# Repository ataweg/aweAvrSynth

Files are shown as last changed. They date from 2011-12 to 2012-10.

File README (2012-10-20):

My version of a virtual analog synthesizer, derived from Meeblip synthesizer, with much enhancements and improvements:
The most important are:
 * Much more of the sound parameters can be controlled via MIDI, the expanded MIDI mapping for my keyboard is based on the knobs and sliders of a QX49
 * Modified waveform tables, A and B have separate oscillator wavetable parameters.
 * Re-introducing some of the switches and controls from Meeblip V1.05, this can be controlled via MIDI
 * Master volume control via MIDI. It can also be raised the volume.
 * Ring Modulator for metallic sounds
 * Noise generator now makes more or less white noise - new algorithm
 * VCFENVMOD now ranging from -128 to +127.
 * PWM generation needs only one sawooth table.
 * Patch 1 has a default setting and can not be overwritten.
 * The volume is keep constant, when OSC B is switched on or off.
 * The button "dco fm" and "anti-alias" sacrificed for "ring modulator" and "transpose"

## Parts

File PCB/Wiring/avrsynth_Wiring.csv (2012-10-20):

ref | value | footprint | Feld1 | Feld2 | Feld3 | Feld4 | Feld5 | Feld6 | Feld7 | Feld8
_P1 | CONN_10
_P2 | CONN_5
_P4 | CONN_8
_P6 | CONN_5
_P9 | CONN_3
_P10 | CONN_3
_P11 | CONN_3
_P13 | CONN_3
_P16 | CONN_3
C1 | 10uF/35V | C1V5
C2 | 100nF | C2
D1 | LED red | LED_5mm
D3 | 1N4148 | DO35-3
D4 | 1N4148 | DO35-3
D5 | 1N4148 | DO35-3
D6 | 1N4148 | DO35-3
D7 | 1N4148 | DO35-3
D8 | 1N4148 | DO35-3
D9 | 1N4148 | DO35-3
D10 | 1N4148 | DO35-3
D11 | 1N4148 | DO35-3
D12 | 1N4148 | DO35-3
D13 | 1N4148 | DO35-3
D14 | 1N4148 | DO35-3
D15 | 1N4148 | DO35-3
D16 | 1N4148 | DO35-3
D17 | 1N4148 | DO35-3
D18 | 1N4148 | DO35-3
D19 | 1N4148 | DO35-3
D20 | 1N4148 | DO35-3
D21 | 1N4148 | DO35-3
D22 | 1N4148 | DO35-3
E1 | KNOPF 14M-4 SW
E2 | KNOPF 14M-4 SW
E3 | KNOPF 14M-4 SW
E4 | KNOPF 14M-4 SW
E5 | KNOPF 14M-4 SW
E6 | KNOPF 14M-4 SW
E7 | KNOPF 14M-4 SW
E8 | KNOPF 14M-4 SW
E9 | KNOPF 20M-4 SW
E11 | DECKEL 14M BL
E12 | DECKEL 14M BL
E13 | DECKEL 14M BL
E14 | DECKEL 14M BL
E15 | DECKEL 14M BL
E16 | DECKEL 14M BL
E17 | DECKEL 14M BL
E18 | DECKEL 14M BL
E19 | DECKEL 20M RT
E21 | ZEIGER 14-1 SW
E22 | ZEIGER 14-1 SW
E23 | ZEIGER 14-1 SW
E24 | ZEIGER 14-1 SW
E25 | ZEIGER 14-1 SW
E26 | ZEIGER 14-1 SW
E27 | ZEIGER 14-1 SW
E28 | ZEIGER 14-1 SW
E29 | ZEIGER 20-1 SW
E33 | Flachbandkabel 10-polig 30cm
E34 | 10-pol Schneidklemm-Buchse
E35 | Gehäuse
E36 | IC Fassungen
J1 | JACK-STEREO 6.35 | Jack-6.35-Stereo
J2 | JACK_2P
J3 | JACK-STEREO-SW 3.5 | Jack-3.5-Stereo-SW
J4 | JACK-STEREO-SW 6.35 | Jack-6.35-Stereo-SW
J5 | USB_2 |  | Reichelt | USB BW | VCC | D+ | D- | GND
P1 | SUBD-F09D
P2 | DIN-BUCHSE-5POL
P3 | DIN-BUCHSE-5POL
P4 | DIN-BUCHSE-5POL
P5 | 9V-BATTERIE-CLIP
P6 | CONN_5X2
RV1 | 47K LIN | poti_4mm | Pollin | 94-240415
RV2 | 47K LIN | poti_4mm | Pollin | 94-240415
RV3 | 47K LIN | poti_4mm | Pollin | 94-240415
RV4 | 47K LIN | poti_4mm | Pollin | 94-240415
RV5 | 47K LIN | poti_4mm | Pollin | 94-240415
RV6 | 47K LIN | poti_4mm | Pollin | 94-240415
RV7 | 47K LIN | poti_4mm | Pollin | 94-240415
RV8 | 47K LIN | poti_4mm | Pollin | 94-240415
RV9 | 47K LOG | poti_4mm
SW1 | SWITCH_INV | Kippschalter | Pollin | 94-420430
SW2 | SWITCH_INV | Kippschalter | Pollin | 94-420430
SW3 | SWITCH_INV | Kippschalter | Pollin | 94-420430
SW4 | SWITCH_INV | Kippschalter | Pollin | 94-420430
SW5 | SWITCH_INV | Kippschalter | Pollin | 94-420430
SW6 | SWITCH_INV | Kippschalter | Pollin | 94-420430
SW7 | SWITCH_INV | Kippschalter | Pollin | 94-420430
SW8 | SWITCH_INV | Kippschalter | Pollin | 94-420430
SW9 | SWITCH_INV | Kippschalter | Pollin | 94-420430
SW10 | SWITCH_INV | Kippschalter | Pollin | 94-420430
SW11 | SWITCH_INV | Kippschalter | Pollin | 94-420430
SW12 | SWITCH_INV | Kippschalter | Pollin | 94-420430
SW13 | SWITCH_INV | Kippschalter | Pollin | 94-420430
SW14 | SWITCH_INV | Kippschalter | Pollin | 94-420430
SW15 | SWITCH_INV | Kippschalter | Pollin | 94-420430
SW16 | SWITCH_INV | Kippschalter | Pollin | 94-420430
SW17 | KDR16 | KDR16
SW18 | PHAP-3301 | PHAP-3301

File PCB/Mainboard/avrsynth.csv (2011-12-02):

ref | value | footprint | Feld1 | Feld2 | Feld3 | Feld4 | Feld5 | Feld6 | Feld7 | Feld8
_NP1 | HOLE | HOLE_32
_NP2 | HOLE | HOLE_32
_NP3 | HOLE | HOLE_32
_NP4 | HOLE | HOLE_32
C1 | 330nF | C2
C2 | 100nF | C2
C3 | 10uF/35V | C1V5
C4 | 100nF | C1
C5 | 100nF | C1
C6 | 33pF KER | C1
C7 | 33pF KER | C1
C8 | 100nF | C1
C9 | 47uF/25V | C1V5
C10 | 100nF | C2
C11 | 10uF/35V | C1V5
C12 | 10uF/35V | C1V5
C13 | 1uF/25V | C1V5
C14 | 220uF/25V | C2V8
C15 | 10nF | C2
C16 | 1nF | C2
C17 | 47nF | C2
C18 | 470pF 2,5% | C2 | Reichelt | FKP-2-1000 470P
C19 | 470pF 2,5% | C2 | Reichelt | FKP-2-1000 470P
C20 | 100nF | C2
C21 | 100nF | C2
C22 | 470uF/25V | C2V10
C23 | 10uF/35V | C1V5
C24 | 1uF/25V | C1V5
C25 | 1uF/25V | C1V5
C26 | 1uF/25V | C1V5
C27 | 1uF/25V | C1V5
C28 | 1uF/25V | C1V5
D1 | 1N4001 | DO41-4
D2 | BAT42 | DO35-3
D4 | 1N4148 | DO35-3
D9 | 1N4148 | DO35-3
IC1 | LM78L05Z | TO92-123
IC2 | ATMEGA32-P | DIP-40__600
IC3 | MAX232 | DIP-16__300
IC4 | LM386 | DIP-8__300
IC5 | AD7302 | DIP-20__300
IC6 | MCP6002 | DIP-8__300
JP1 | JUMPER | pin_array_2x1
L1 | 10uH | R5
OK1 | 6N138 | DIP-8__300
P1 | CONN_10 | PS25_10G
P2 | CONN_5 | PS25_5G
P3 | CONN_3X2 | pin_array_3x2
P4 | CONN_8 | PS25_8G
P6 | CONN_5 | PS25_5G
P9 | CONN_3 | PS25_3G
P10 | CONN_3 | PS25_3G
P11 | CONN_3 | PS25_3G
P12 | CONN_5X2 | pin_array_5x2
P14 | CONN_3 | PS25_3G
P16 | CONN_3 | PS25_3G
Q5 | BC557B | TO92
Q6 | BC547C | TO92
Q7 | BC557B | TO92
Q8 | BC547C | TO92
R1 | 10K | R4
R2 | 1K 0,1% | R4
R3 | 220R | R4
R4 | 270K 0,1% | R4
R11 | 10K 0,1% | R4
R13 | 4K7 1% | R4
R14 | 24K 1% | R4
R16 | 10R | R4
R21 | 22R | R4
R23 | 10K | R4
R24 | 470R | R4
R25 | 470R | R4
R26 | 220R | R4
R27 | 220R | R4
R28 | 220R | R4
R29 | 4K7 | R4
R30 | 1K5 | R4
R31 | 33K | R4
R32 | 220R | R4
R33 | 220R | R4
R34 | 15K | R4
R35 | 220R | R4
R36 | 220R | R4
R37 | 220R | R4
R38 | 4K7 | R4
R39 | 1K5 | R4
R40 | 33K | R4
R45 | 10K | R4
R46 | 10K | R4
X1 | 16MHz | HC-49V

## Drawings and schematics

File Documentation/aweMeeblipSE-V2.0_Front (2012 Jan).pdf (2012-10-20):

## Axel Werner

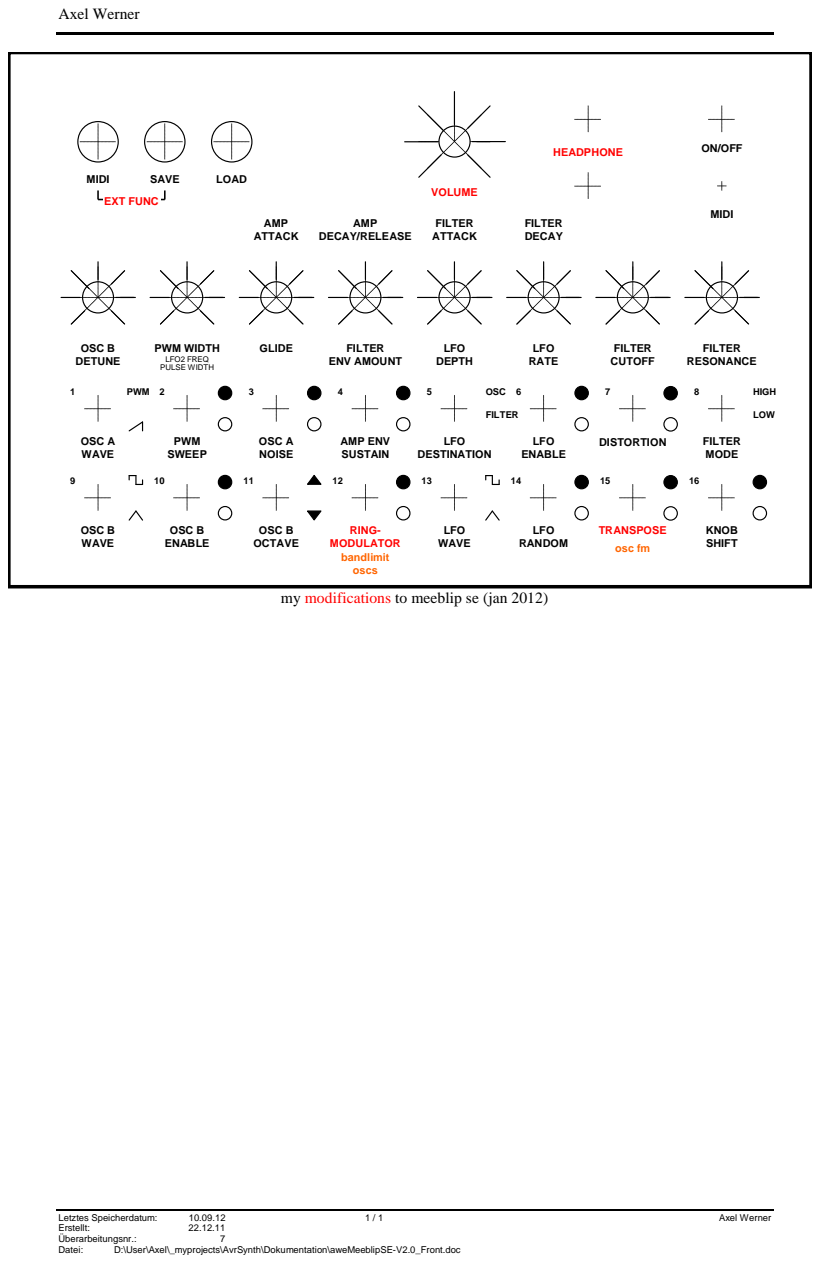
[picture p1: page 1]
Letztes Speicherdatum:; Axel Werner; Erstellt:; Überarbeitungsnr.:; Datei:; D:\User\Axel\_myprojects\AvrSynth\Dokumentation\aweMeeblipSE-V2.0_Front.doc; OSC B DETUNE; PWM WIDTH LFO2 FREQ PULSE WIDTH; GLIDE; FILTER; ENV AMOUNT; LFO DEPTH; LFO RATE; FILTER CUTOFF; FILTER RESONANCE; OSC A WAVE; PWM SWEEP; AMP ENV SUSTAIN; LFO DESTINATION; LFO ENABLE; OSC A NOISE; FILTER MODE; OSC B WAVE; OSC B ENABLE; OSC B OCTAVE; RING- MODULATOR; LFO WAVE; LFO RANDOM; KNOB SHIFT; VOLUME; AMP ATTACK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

my modifications to meeblip se (jan 2012)

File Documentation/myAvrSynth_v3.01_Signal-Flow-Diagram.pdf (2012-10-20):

## LFO

## DCO A

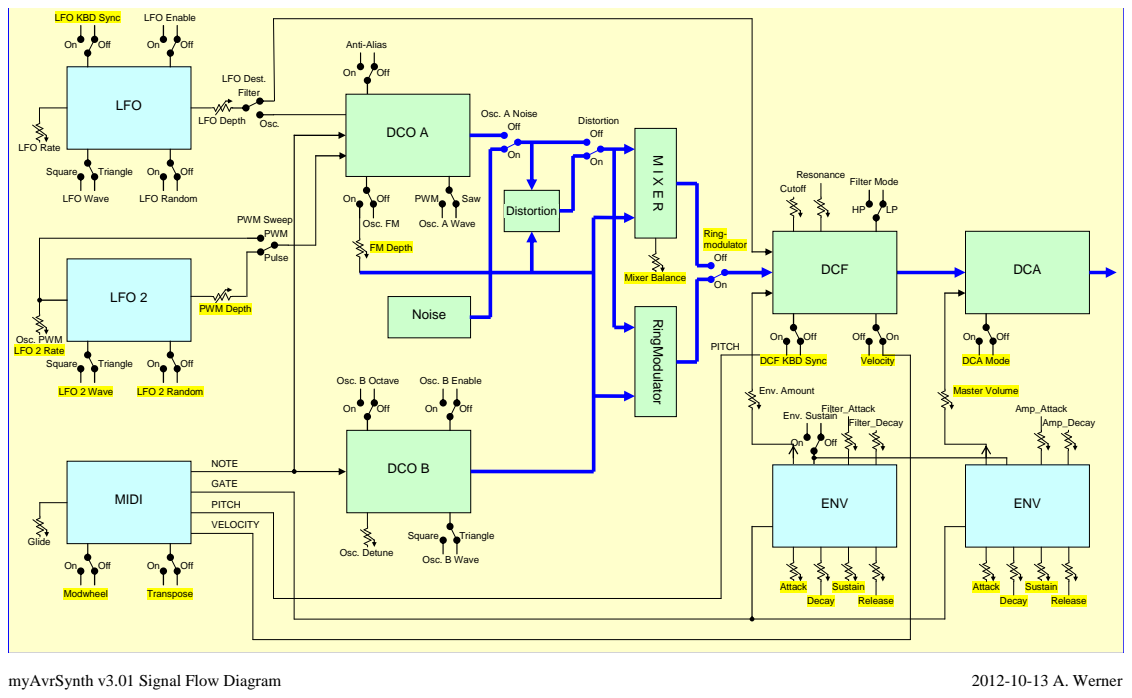
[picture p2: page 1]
MIDI; Glide; Off; Transpose; Modwheel; GATE; NOTE; PITCH; VELOCITY; Noise; DCO B; Osc. Detune; Triangle; Osc. B Wave; Square; Osc. B Enable; Osc. B Octave; LFO Rate; Filter; LFO Dest.; LFO Enable; LFO Wave; LFO Random; Pulse; PWM Sweep PWM; PWM Depth; LFO 2 Rate; LFO 2; LFO 2 Wave; LFO 2 Random; Osc. PWM; Anti-Alias; Osc. FM; FM Depth; Saw; Osc. A Wave; PWM; RingModulator M I X E R; Osc. A Noise; Distortion; Mixer Balance; Ring- modulator; Env. Amount; Master Volume; DCA; DCA Mode; Velocity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

LFO KBD Sync

Osc. LFO Depth

DCF KBD Sync

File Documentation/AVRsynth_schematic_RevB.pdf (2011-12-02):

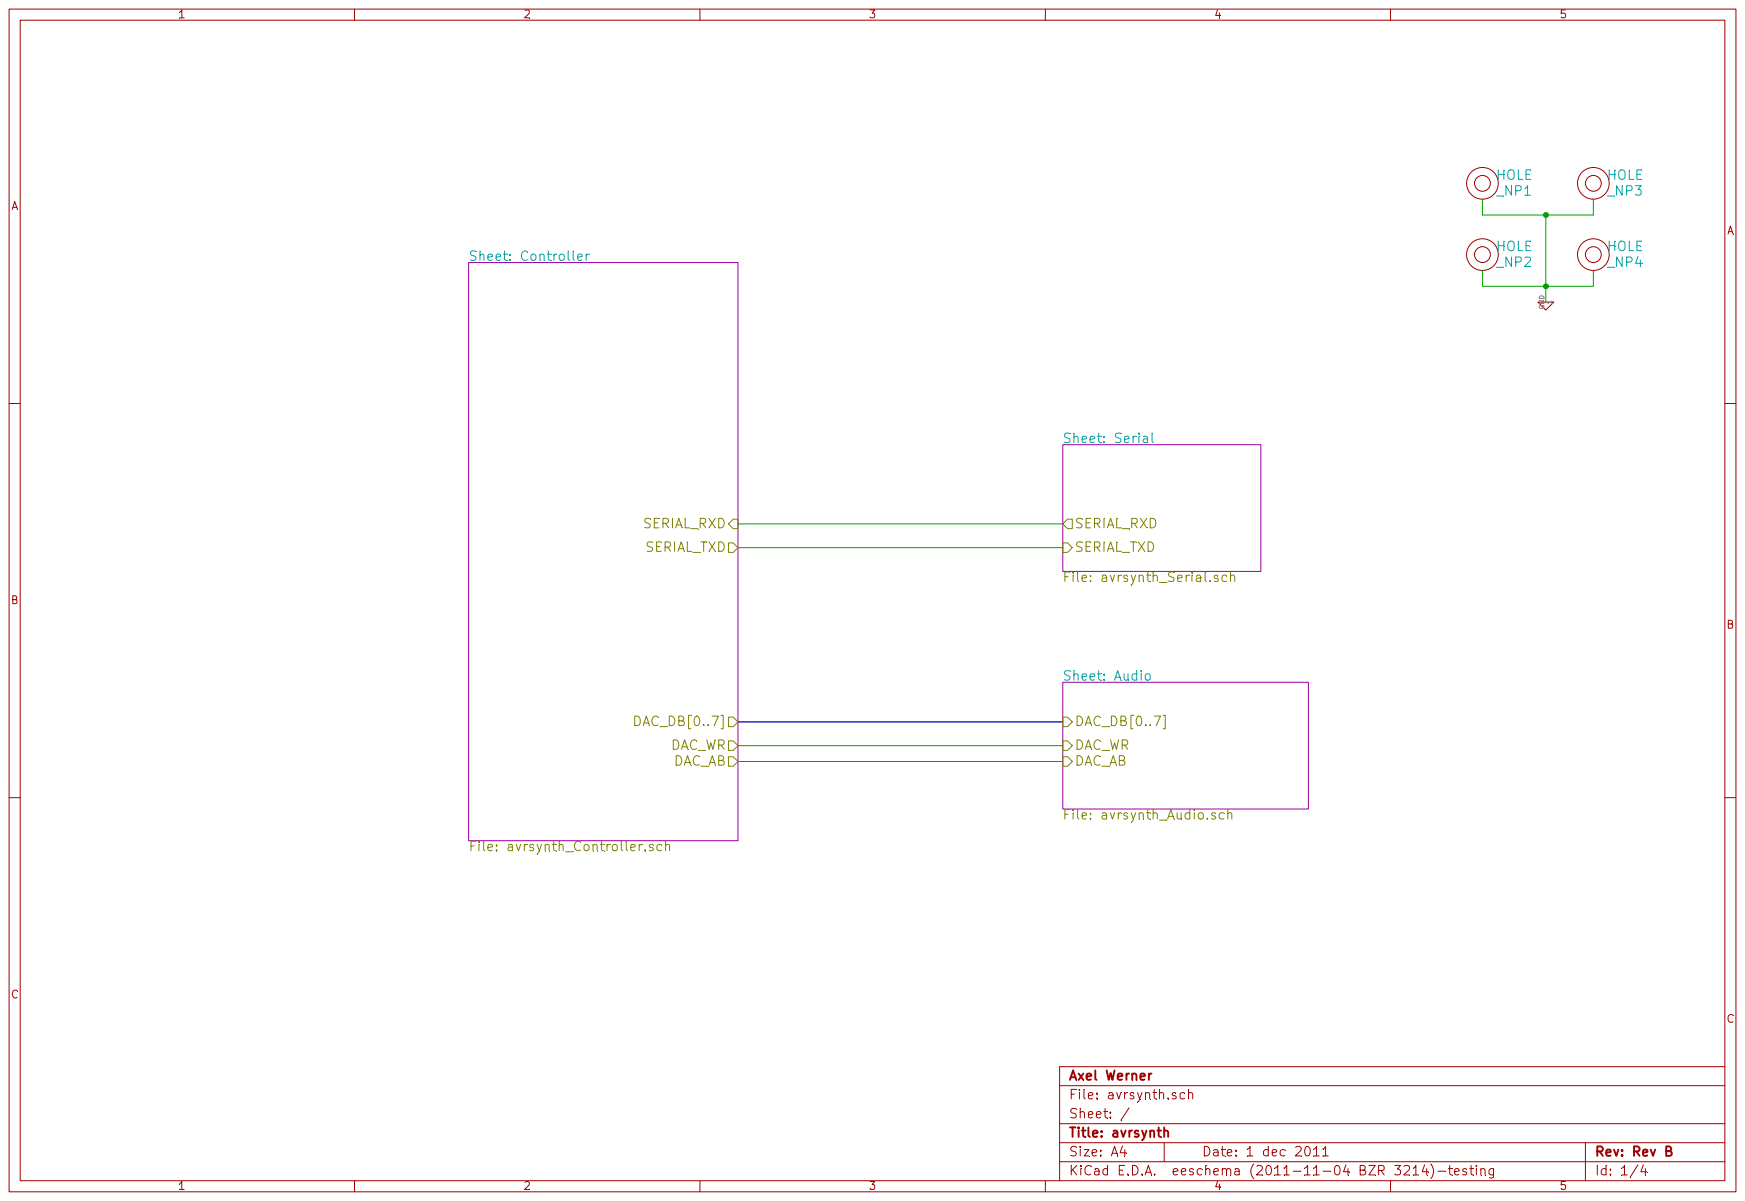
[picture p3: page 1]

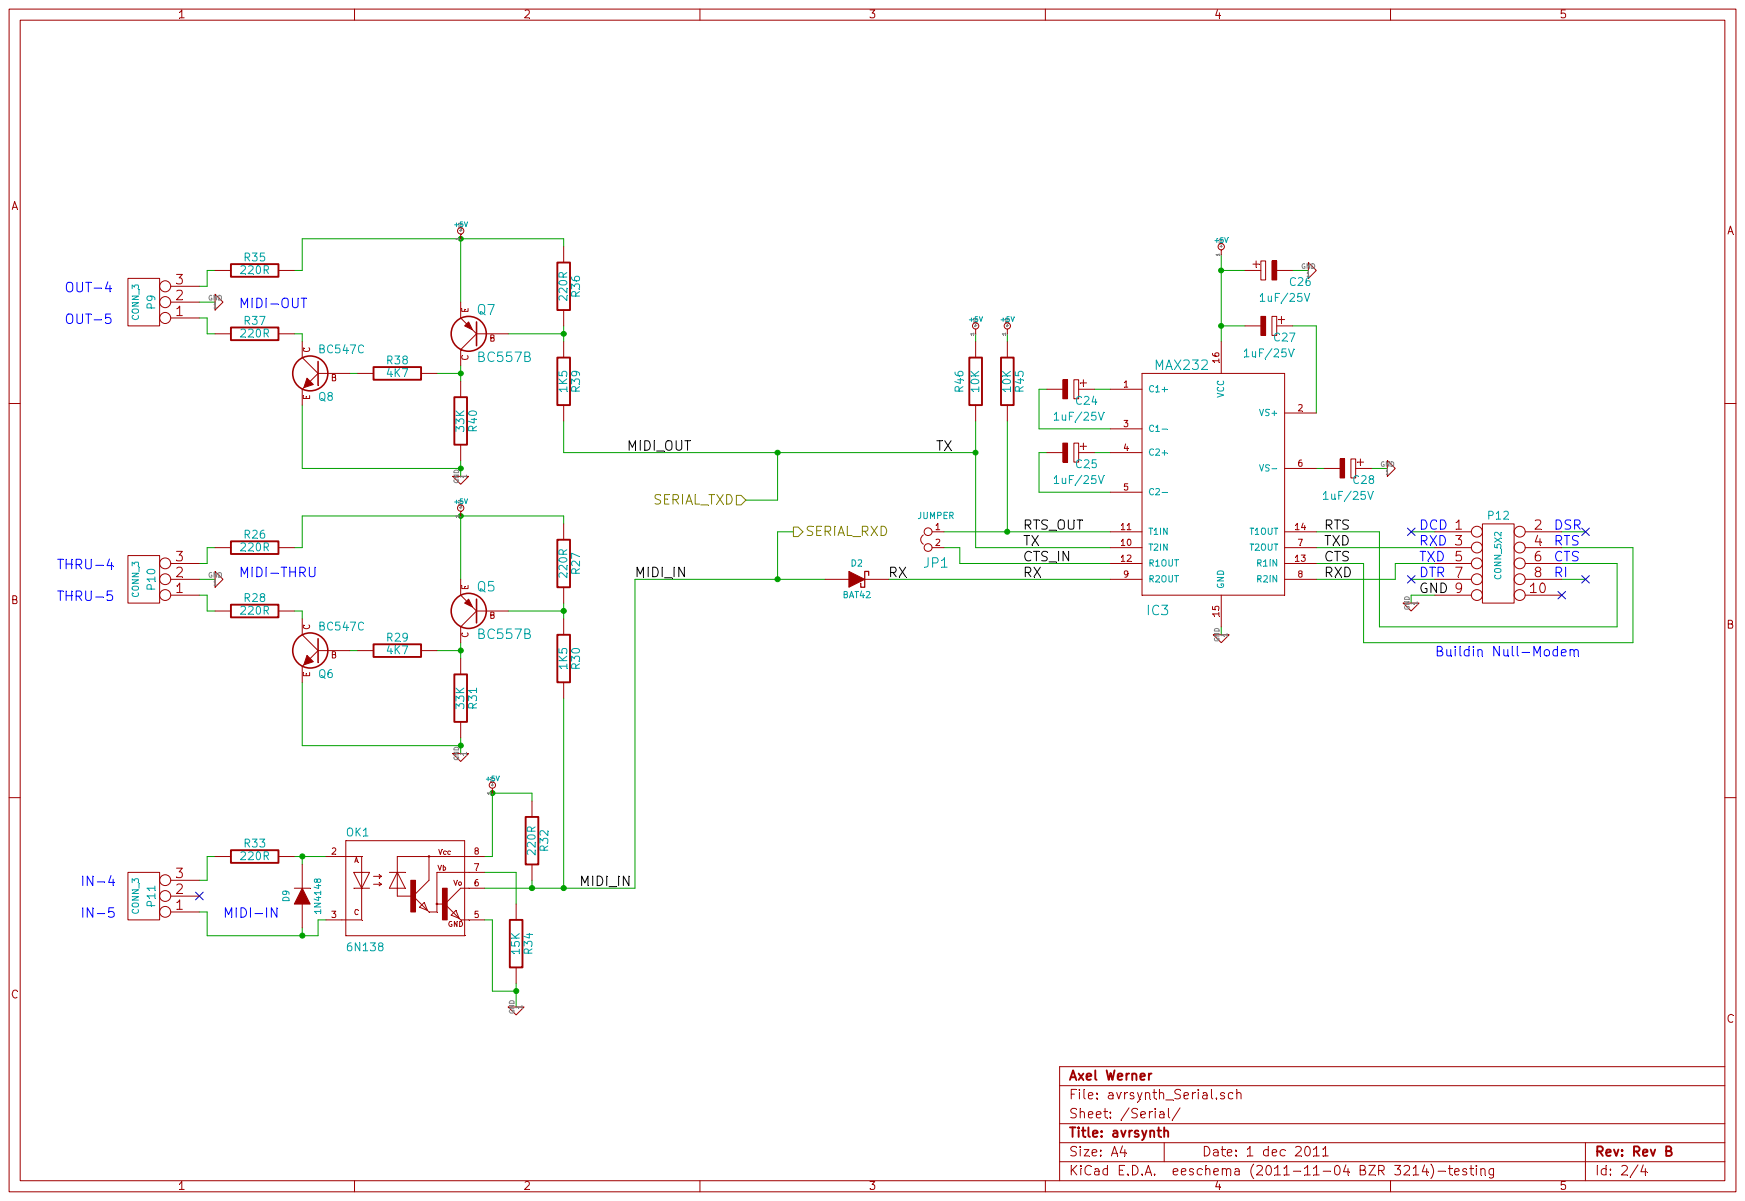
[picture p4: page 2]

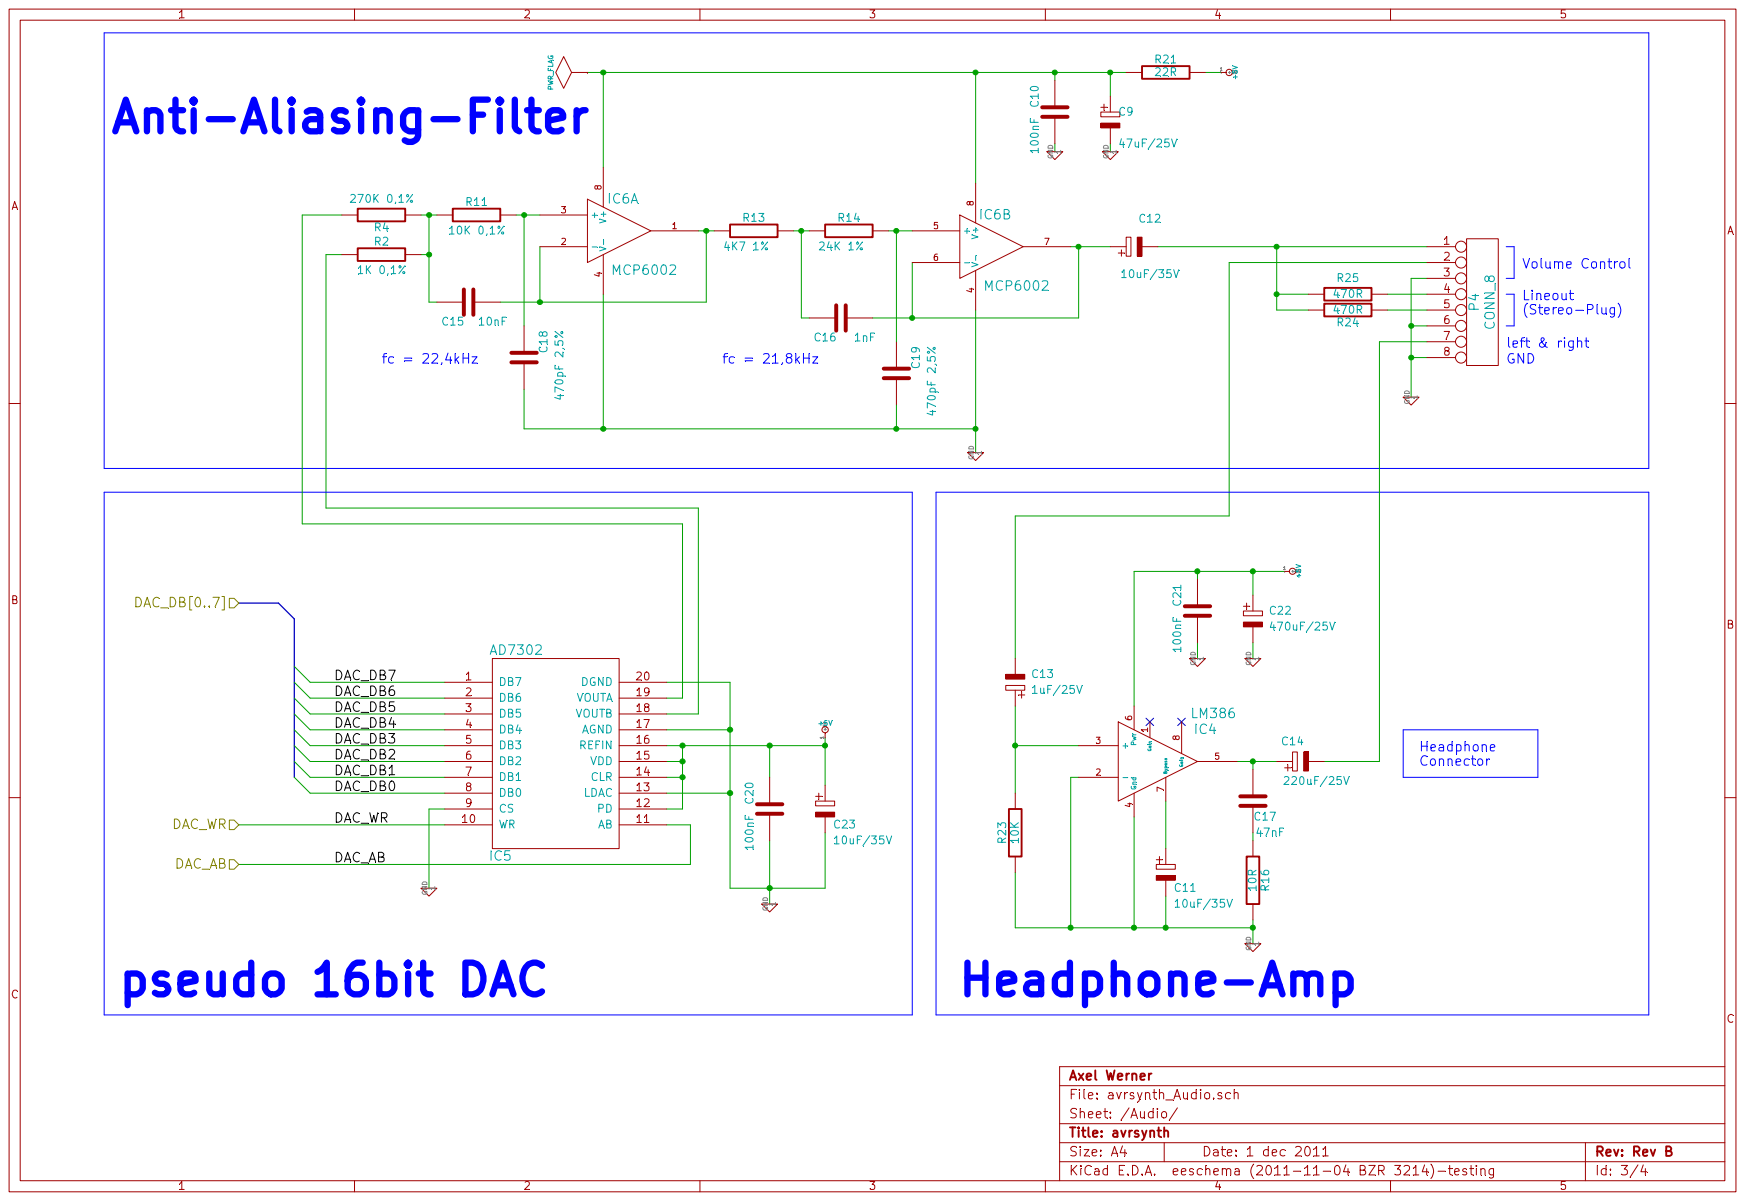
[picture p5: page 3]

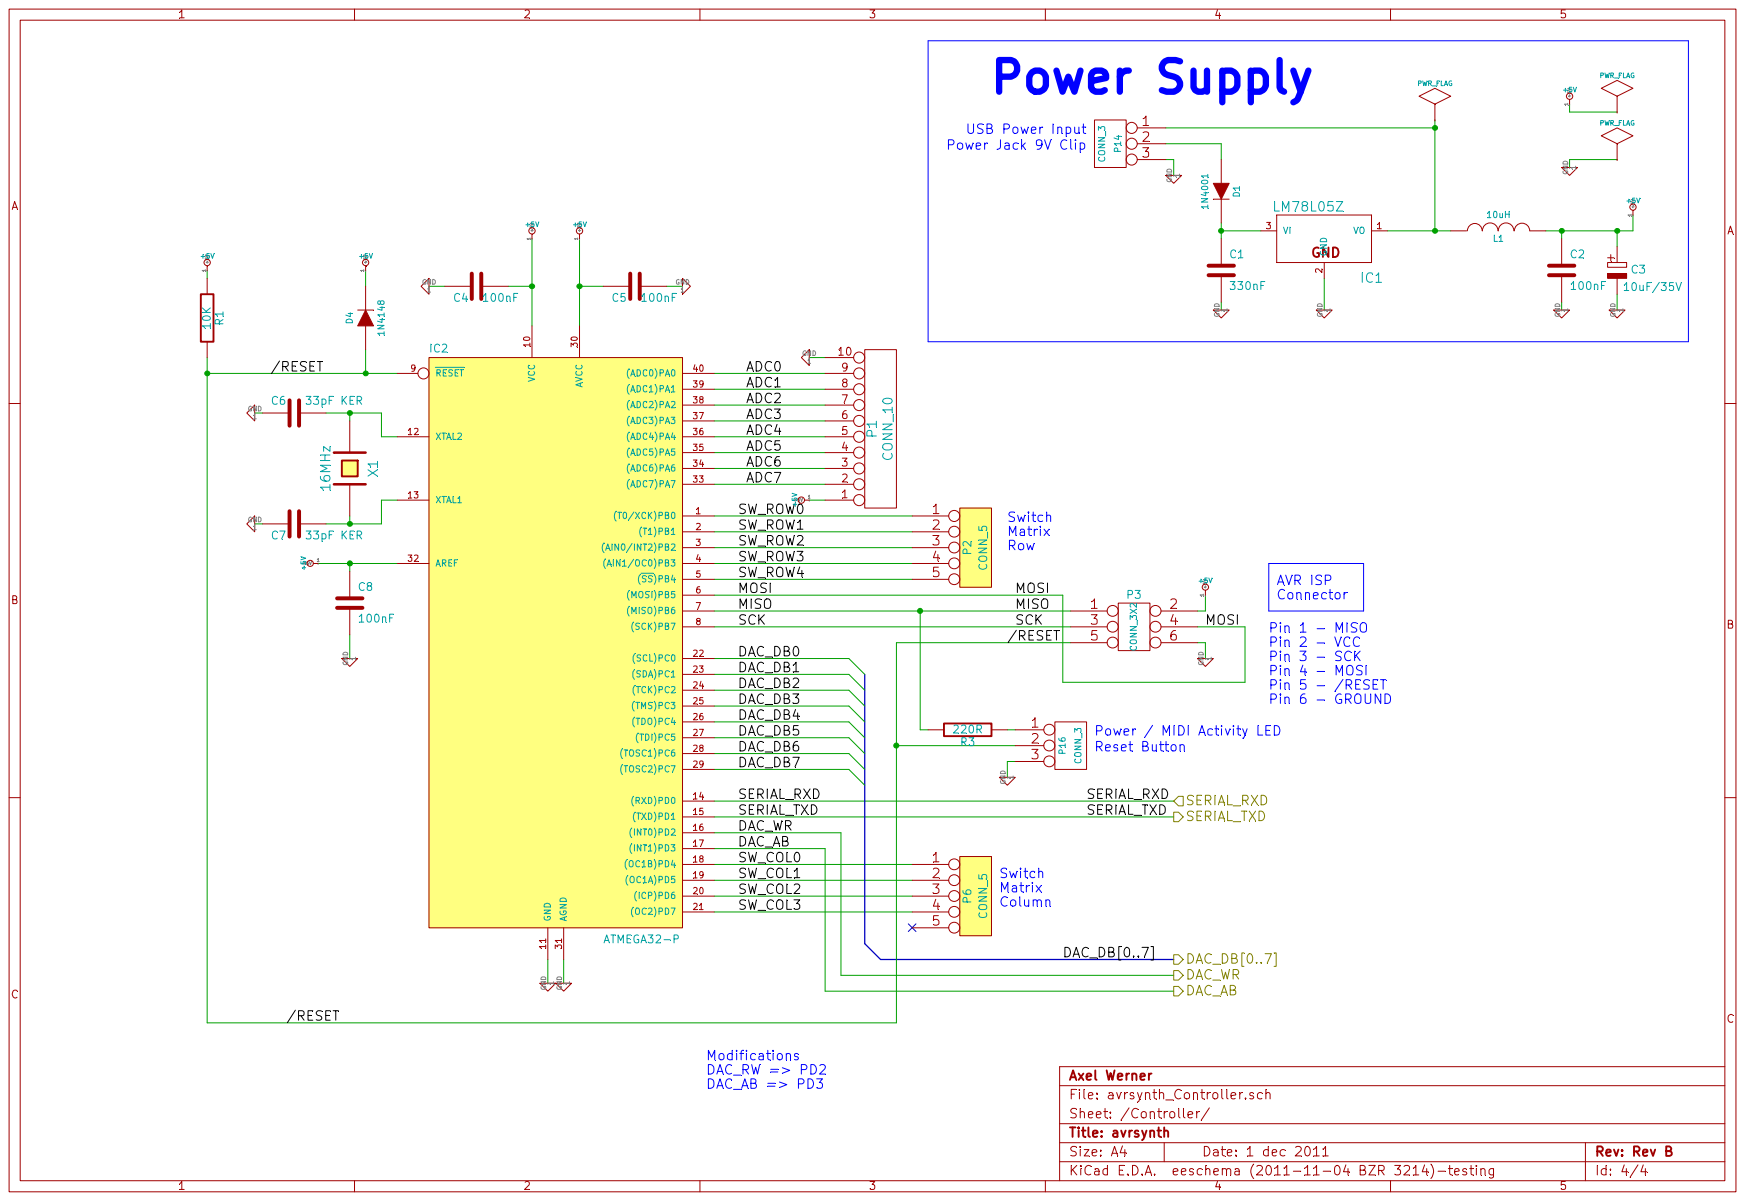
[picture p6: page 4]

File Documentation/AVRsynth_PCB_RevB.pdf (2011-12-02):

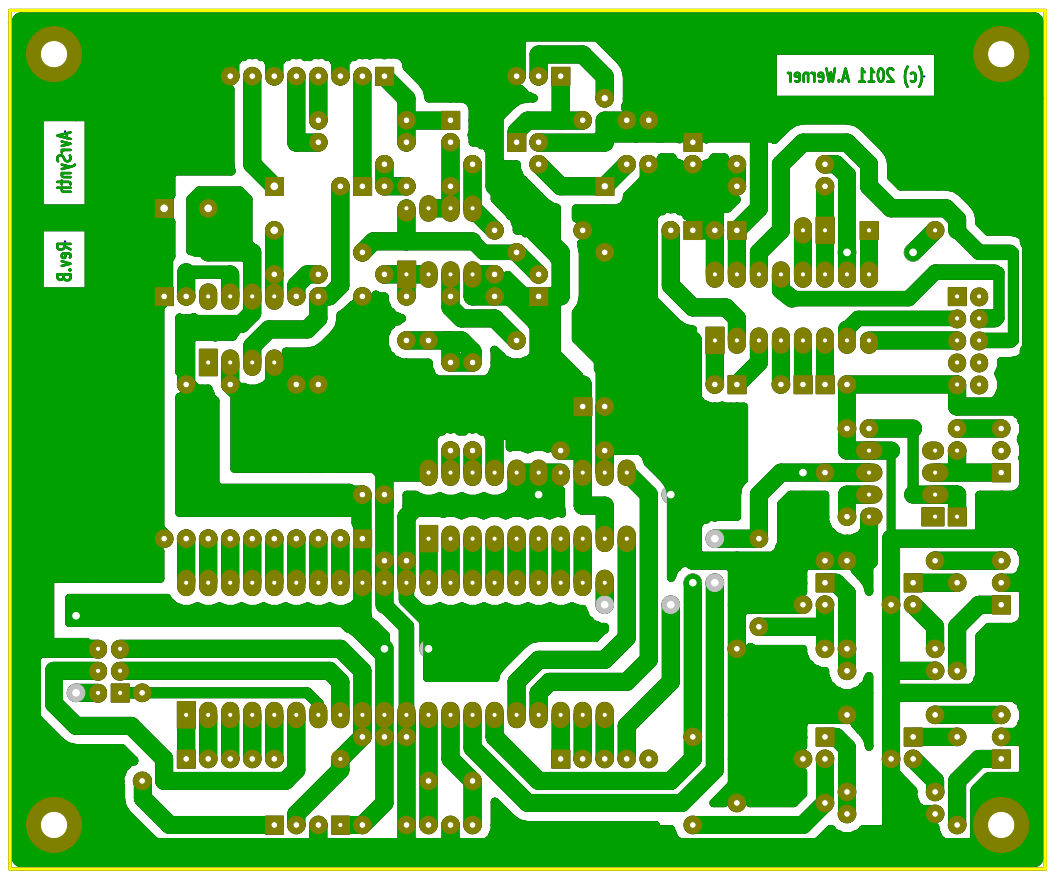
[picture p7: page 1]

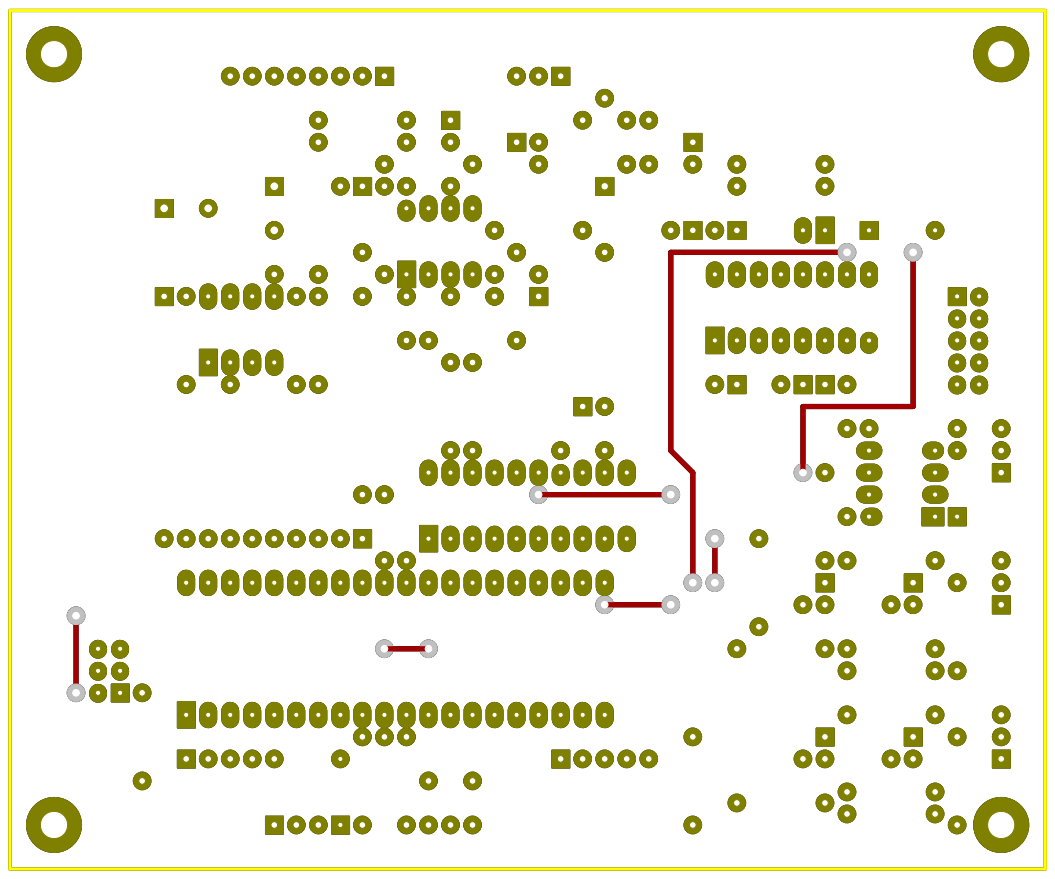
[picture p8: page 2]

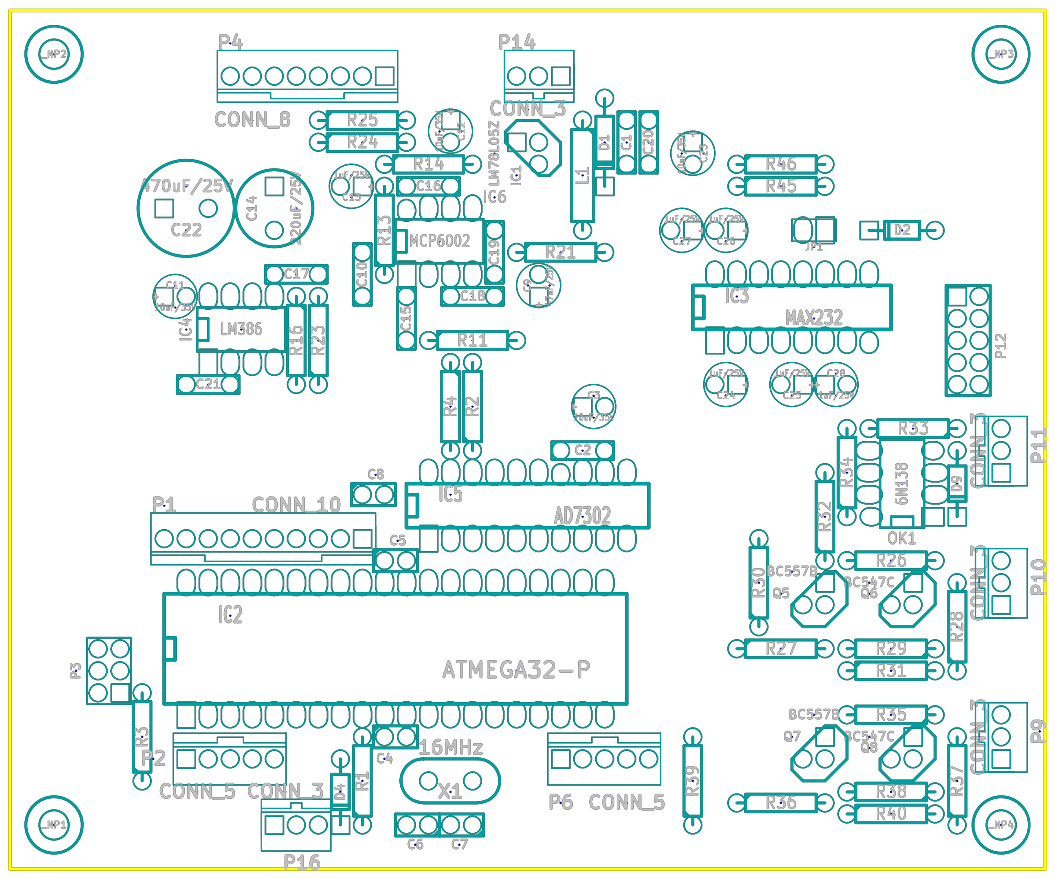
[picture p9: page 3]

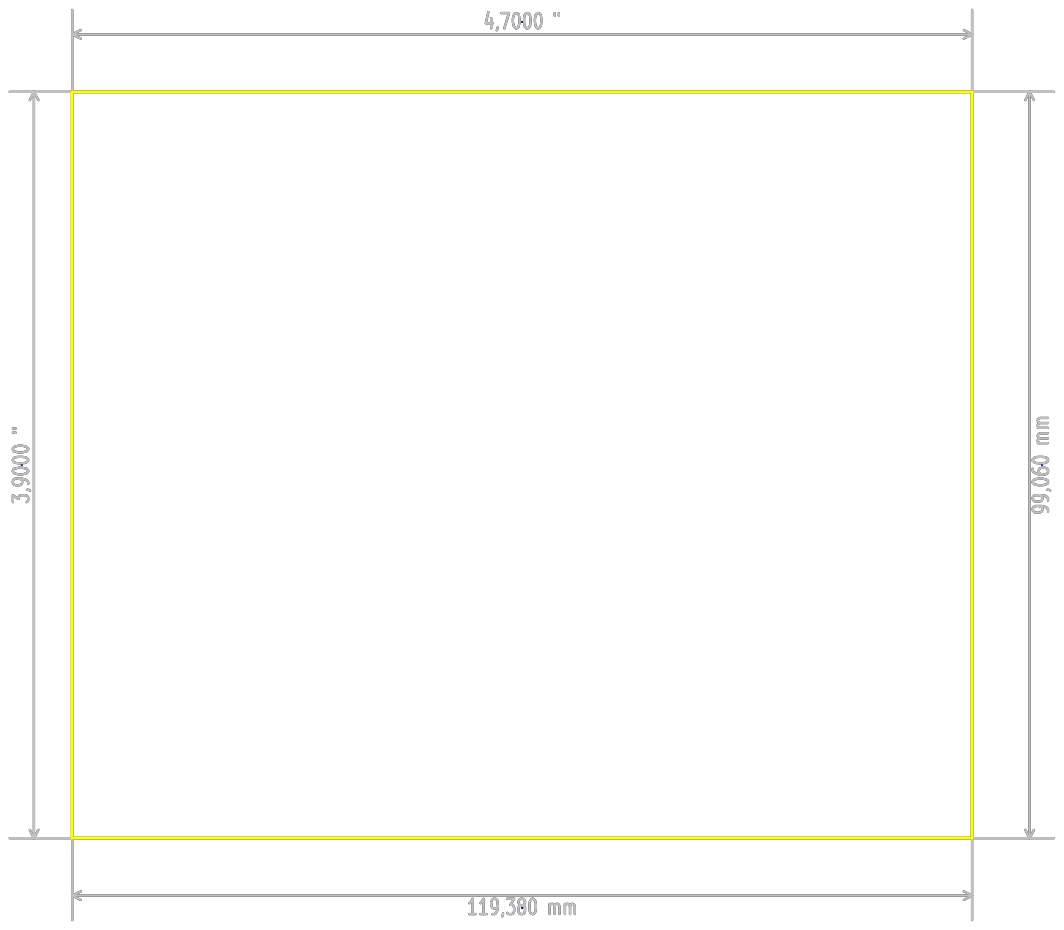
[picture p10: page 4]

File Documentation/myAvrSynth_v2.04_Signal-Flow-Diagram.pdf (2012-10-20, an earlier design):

## LFO

## DCO A

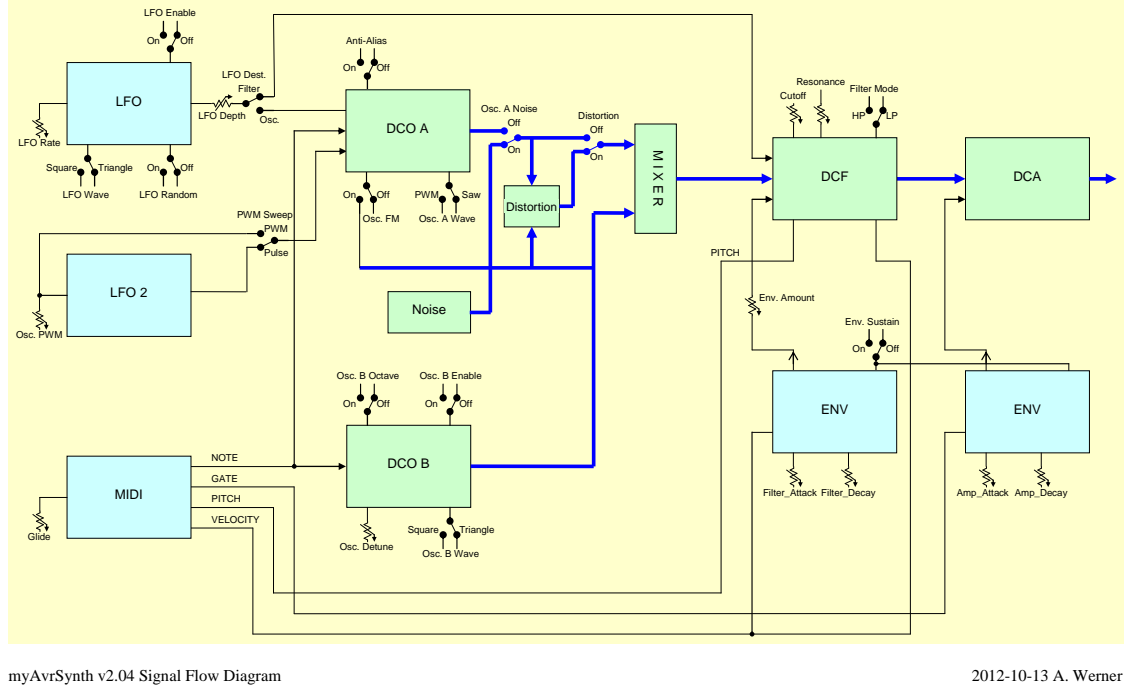
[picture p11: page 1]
MIDI; Glide; GATE; NOTE; PITCH; VELOCITY; Noise; DCO B; Osc. Detune; Triangle; Osc. B Wave; Square; Off; Osc. B Enable; Osc. B Octave; LFO Rate; Filter; LFO Dest.; LFO Enable; LFO Wave; LFO Random; Pulse; PWM Sweep PWM; LFO 2; Osc. PWM; Anti-Alias; Osc. FM; Saw; Osc. A Wave; PWM; Osc. A Noise; Distortion; Env. Amount; DCA; DCF; Filter Mode; Cutoff; Resonance; Env. Sustain; ENV; Filter_Attack Filter_Decay; Amp_Attack Amp_Decay; myAvrSynth v2.04 Signal Flow Diagram; 2012-10-13 A. Werner

Osc. LFO Depth

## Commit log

2011-12-02 Excel sheets with MeeBlip SE waveforms
    [Wavetables.xls]
2011-12-02 Schematic and PCB for aweAvrSynth
    [avrsynth.brd, avrsynth.csv, avrsynth.sch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]
2011-12-02 add pdf for PCB
2011-12-22 my meeblip v2.02 hack, done a lot of optimisations and improvements
    [FourierWavetables.csv, FourierWavetables.xls]
2011-12-22 wavetable generation with perl
    [FourierWavetables.csv, FourierWavetables.xls]
2012-01-04 check in version 2011-01-04
    * move calculation of scaled_resonance from isr to mainloop
    * change q offset from 32 to 24, lower values will cause clipping
    * use better rounding for calculated table TAB_VCF
    * change index of some midi cc
    * change bit SW_MIX_RING position of in variable PATCH_SWITCH3
    * for extended button functions let LED blink faster
2012-10-20 clean up repository, remove all files
    [FourierWavetables.csv, FourierWavetables.xls, Wavetables.xls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]
2012-10-20 My version of a virtual analog synthesizer, derived from Meeblip synthesizer, with much enhancements and improvements.
    [FourierWavetables.csv, FourierWavetables.xls, avrsynth.brd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]
